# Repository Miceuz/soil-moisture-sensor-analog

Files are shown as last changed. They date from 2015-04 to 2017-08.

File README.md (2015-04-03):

# soil-moisture-sensor-analog

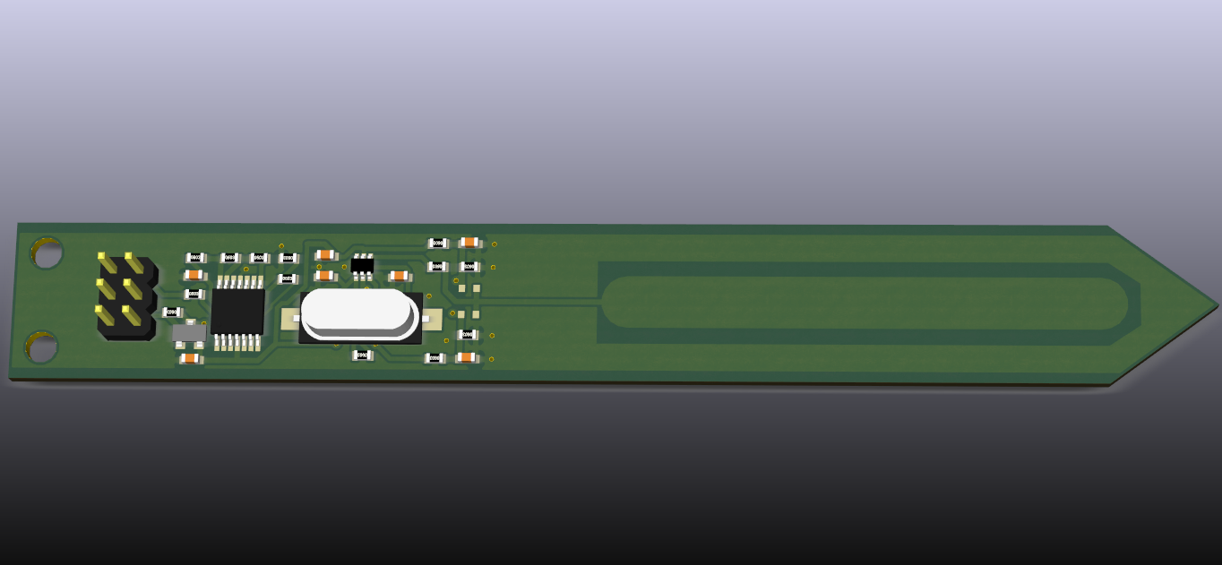
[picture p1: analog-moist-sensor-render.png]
3D render


Analog soil moisture sensor. Continuation of my [Chirp](https://github.com/Miceuz/PlantWateringAlarm) project. The idea behind this version is to provide an analog output for the microcontroller and increase the resolution by detecting both peaks and dips of filtered waveform.

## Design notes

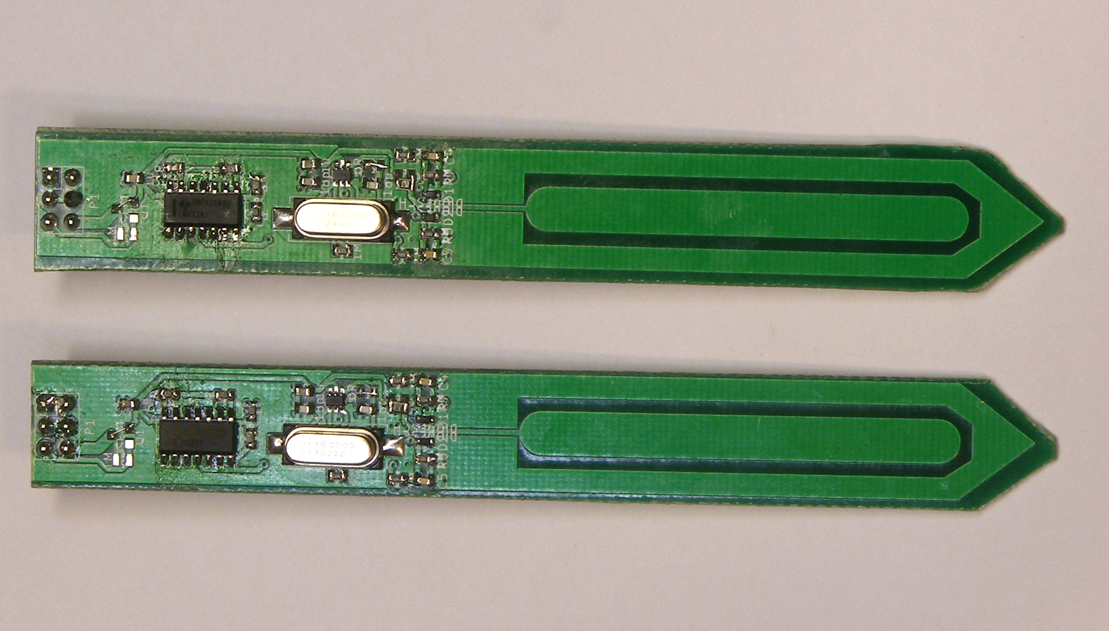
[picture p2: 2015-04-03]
prototype1.png

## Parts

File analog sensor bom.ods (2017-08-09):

Available | Manufacturer No | Amount | Description | Price 400 |  | Price bulk | Bulk size | Vendor | Vendor No
X | NC7WZU04P6X | 1 | Unbuffered single stage dual hex inverter | 0.105 | 0.105 | 0.065 | 3000 | Mouser | 512-NC7WZU04P6X | Iš aliexpress po 0.09€ 200vnt
 | ACASA100221002P100 | 0 | Resistor network 10k 0.5% | 0.3769 | 0 |  |  | Digikey | ACASA-10K/10K-2CT-ND
 | MCRE000217 | 0 | Resistor network 10k 1% | 0.009 | 0 |  |  | Farnel | 1711701RL
X | ERA3AEB1872V | 4 | Resistor 0.1% | 0.03 | 0.12 |  |  | Farnel | 1810244
X | LMV324IDT | 1 | Quad opamp | 0.258 | 0.258 |  |  | Farnel | 2463665RL
X | MCRSD16000F183000RR | 1 | CRYSTAL, 16MHZ, 18PF, HC49-US, SMD | 0.133 | 0.133 |  |  |  | 2395958
X | PCB | 1 |  | 1 | 1
x |  |  | 1M resistor
x |  |  | 1u cap
x |  |  | 1n cap
X |  |  | MOSFET_P
x |  |  | DIODE SCHOTTKY sod-523
x |  |  | 18p cap
x |  |  | 330 resistor
 |  |  |  | total | 1.616
 |  |  |  | total+vat | 1.95536
 |  |  |  | manufacturing | 2
 |  |  |  |  | 3.95536
 |  |  |  | wholesale | 6.328576
 |  |  |  | retail | 10.1257216

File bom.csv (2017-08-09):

Id | Designator | Package | Quantity | Designation | Supplier and ref
1 | C1,C2 | SMD-0603_c | 2 | 18p
2 | U1 | sc70-6 | 1 | NC7WZU04P6
3 | R1,R3,R5,R6,R7,R8 | SMD-0603_r | 6 | 1M
4 | C3,C6 | SMD-0603_c | 2 | 1u
5 | X1 | Crystal_HC49-SD_SMD | 1 | 16MHz
6 | R2 | SMD-0603_r | 1 | 0R
7 | R4,R9,R10,R11,R12 | SMD-0603_r | 5 | R
8 | C4,C5 | SMD-0603_c | 2 | 1n
9 | P1 | Pin_Header_Straight_2x03 | 1 | CONN_01X06
10 | Q1 | SOT-23-GDS | 1 | MOSFET_P
11 | D1,D2 | SOD-523 | 2 | DIODESCH
12 | U2 | SOIC-14_W | 1 | LM324

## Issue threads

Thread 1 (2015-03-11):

Some minor Q's

tj000b, 2015-03-11:
Hello Miceuz

I am looking at your wonderful project analog project because I would like to avoid the AtTiny which is on the chirp sensor I already own.

Looking through the BOM list i am confused about resistor values for R2, R4, R9 and R10. Maybe you could shed some light on this?

Also i figure that "OUT" is an analog voltage between 0 and VCC(?) somehow proportional to soil moisture content, right?

Also what is the lower limiting factor for operation voltage, if its the LM324 with its 3V minimum then maybe if I swap it for i.e. a LMV324M (min voltage 2.7V) then i might be able to get readings supplying only 2.75V?

I know its alot of questions, I hop you will find time to reply :)

Miceuz, 2015-03-11:
-----BEGIN PGP SIGNED MESSAGE-----
Hash: SHA1

Hi!

R2 might be needed, might be not, depends on how successful is the
oscillator to start and how much ringing does it produce. Note that
resistor is marked zero ohms for now, it's just a place-holder.

R4 will have to be selected by experimentation. It depends on
frequency and capacitance of sensor track. This is a new board I'm
still waiting from PCB house, so I don't know the value yet.

R9, R10, R11, R12 should be high tolerance resistors of the same
value. Something like 10k should work.

Yes, OUT is a voltage proportional to soil moisture. Regarding the
operating voltage, frankly I didn't give much thought to it. There are
two active devices - LMV324 and NC7WZU04. NC7WZU04 works down to 1.65V
but it's not clear if the oscillator will start properly (it should,
but "don't assume anything") then it's the main opamp, so basically
you might be right. Note, that you can replace LMV324 to any quad
opamp of better performance if you want, LMV324 is selscted as the
best from the worst for low price point.

Good luck and let me know how it goes, I should get the boards in
couple of weeks and try them myself.

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

- --
Albertas Mickėnas

http://technariumas.lt
http://wemakethings.net
https://www.tindie.com/stores/miceuz/
-----BEGIN PGP SIGNATURE-----
Version: GnuPG v1

iEYEARECAAYFAlUAblUACgkQJ2lgtwRRHqEDWQCfZb6bbZyAwroSuSLcCd2873Ef
7nIAnjgZ4WeUpYGtEUdiOXAVQuk4lkdR
=GNpF
-----END PGP SIGNATURE-----

tj000b, 2015-03-16:
Hi and thanks for the reply. Very useful!! Interesting that you are getting the boards, looking forward to seeing what happens, i am excited to find out if they work properly :). I will report back when i know more about min operating voltage, however unfortunatly i think it will be atleast a couple of weeks before i have the hardware ready.

tj000b, 2015-05-05:
Hi again
I am just about to order some of the boards. However i noticed that you have removed the differential opAmp and have replaced the "OUT" with SENSE_HIGH_OUT and SENSE_LOW_OUT.

I am going to use it with a microcontroller. Can you shed some light on how to read and convert SENSE_HIGH_OUT and SENSE_LOW_OUT to soil moisture?
And maybe tell why you removed the differential opAmp? :)

Have a nice day!

Miceuz, 2015-05-06:
Check the diff amp branch - https://github.com/Miceuz/soil-moisture-sensor-analog/tree/feature-diff-amp the diff amp is back. I was thinking about transmitting differential signal over the wire, but then thought it's a bit awkward.

tj000b, 2015-05-07:
Hi Miceuz, thanks for the comment! I know you have a day time job now, but I am glad that you still have your chirp hobby! :D

I was trying to hack one of my v2.5 i2c version of the plant watering alarm today. I wanted to remove the ATTiny and just use pins from another uC (electric imp), running 3.3V.
I desoldered the ATTiny and put my 1Mhz PWM pin directly to CLK_OUT and one of my ADC in pins to CAPACITANCE_V.

However my readings are somewhat unsteady doing it like this, so I was wondering if you where doing some signal processing?

Also I get low ADC values when i put the sensor in water and high when i leave it in free air.
Does that make sense?

Cheers!
tj000b

Miceuz, 2015-05-07:
Its not a hobby any more ,)

Hm, its strange you have unstable readings. Maybe high output impedance of excitarion signal? Long wires? Im not doing anything extra to the signal.

Low values in water is normal as capacitance becomes bigger, so square wave is filtered more and peaks are getting lower. Im subtracting from 255 in my original firmware to return bigger number for more water.

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

--
Sent from my Android device with K-9 Mail. Please excuse my brevity.

tj000b, 2015-05-08:
Im glad to here you are making some money of this stuff. Its good work! :)

I am not sure about the output impedance of the GPIO pin on my uC. I do however have a few centermeters of wire from pins on my uC to the chirp, so maybe they are screwing things up, acting as antennas or something.

I will draw up and order some PCBs, that way I can see if the long floating wires are the cause of the problem :)

Adjusting dutycyle of the excitation signal also plays a role.

My readings are not all that unsteady, but once in a while a strange one sneaks in:
2015-05-08 10:19:27 UTC+2	[Device]	18276
2015-05-08 10:19:31 UTC+2	[Device]	20485
2015-05-08 10:19:35 UTC+2	[Device]	18116
2015-05-08 10:19:39 UTC+2	[Device]	18148
2015-05-08 10:19:43 UTC+2	[Device]	24918
2015-05-08 10:19:47 UTC+2	[Device]	18164
2015-05-08 10:19:51 UTC+2	[Device]	18308

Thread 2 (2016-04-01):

How does it work?

dzuy65, 2016-04-01:
What is the principal technology behind this device?  I assume it's capacitance, FDR.  What frequency do you use?  What is the required input voltage?  Output?

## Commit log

2015-02-04 Initial commit - the first go at PCB
    [analog-moist-sensor.kicad_pcb, analog-moist-sensor.sch]
2015-02-04 add some documentation
    [analog sensor bom.ods, analog-moist-sensor.kicad_pcb]
2015-02-05 Change 2 opamp buffer to a difference amplifier made of lmv324
    [analog-moist-sensor.kicad_pcb, analog-moist-sensor.sch]
2015-02-16 add bom, some pcb changes
    [analog sensor bom.ods, analog-moist-sensor.kicad_pcb]
2015-02-16 Correct sensor size, add ground plane around it
    [analog-moist-sensor.kicad_pcb]
2015-02-17 Last touch
    [analog-moist-sensor.kicad_pcb]
2015-02-17 Add pannel file
    [analog-moist-sensor panel.kicad_pcb]
2015-02-17 Add gerbers as they were sent to Seeedstudio
    [analog-moist-sensor panel-B_Cu.gbr, analog-moist-sensor panel-B_Mask.gbr, analog-moist-sensor panel-B_SilkS.gbr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]
2015-03-25 Stupid kicad library update broke the schematics. Duhgit add .
    [analog-moist-sensor.sch]
2015-03-26 Add docu for precision resistors
2015-03-26 Add a 15 low pass filter and use the last opamp as a buffer. Also add an output protection resistor. Also specify missing resistor values
    [analog-moist-sensor.sch]
2015-03-26 Fix missing connection
    [analog-moist-sensor.sch]
2015-03-26 Use the new known footprints for resistors and capacitors
2015-03-26 Rip up and start rerouting with new opamp package
    [analog-moist-sensor.kicad_pcb]
2017-08-09 Some forgotten changes before manufacturing
    [analog sensor bom.ods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]
